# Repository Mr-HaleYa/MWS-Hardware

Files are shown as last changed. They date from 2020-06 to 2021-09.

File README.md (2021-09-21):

# My Water Site - Hardware

[3D Files](3D_models/README.md)

# PCB

### [V4.0](https://github.com/Mr-HaleYa/MyWater_Misc/tree/master/PCB#v40)

Front             |  Back
:-------------------------:|:-------------------------:
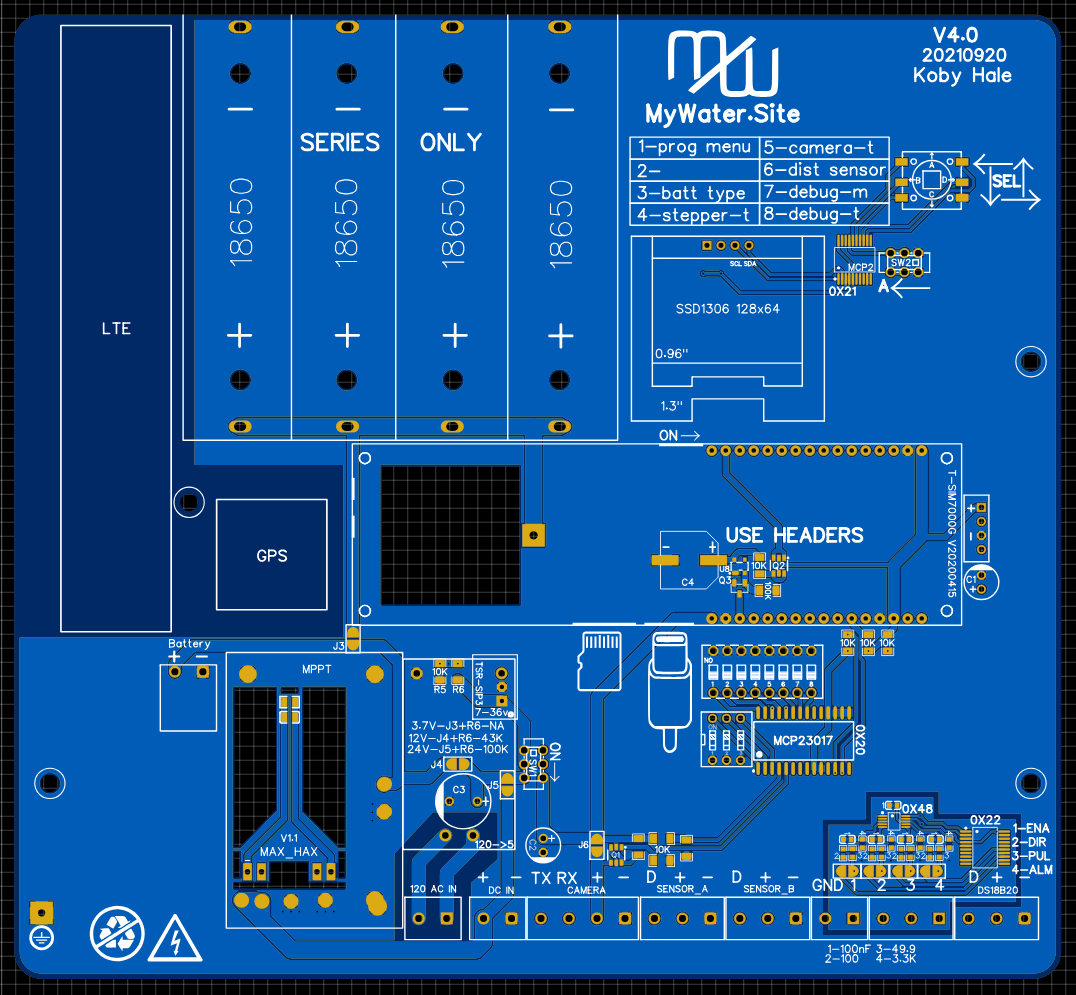
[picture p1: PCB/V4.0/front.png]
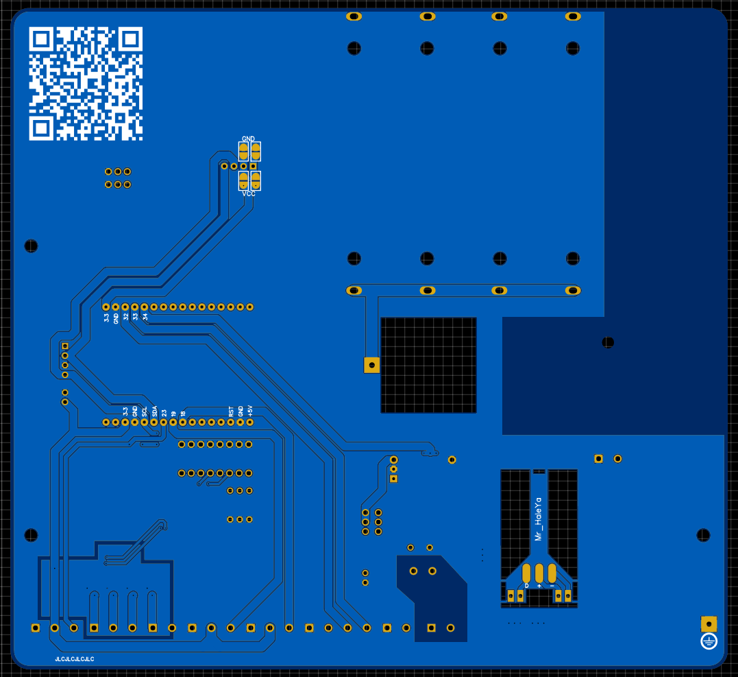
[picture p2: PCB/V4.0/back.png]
  |  

### [V3.2](https://github.com/Mr-HaleYa/MyWater_Misc/tree/master/PCB#v32)

Front             |  Back
:-------------------------:|:-------------------------:
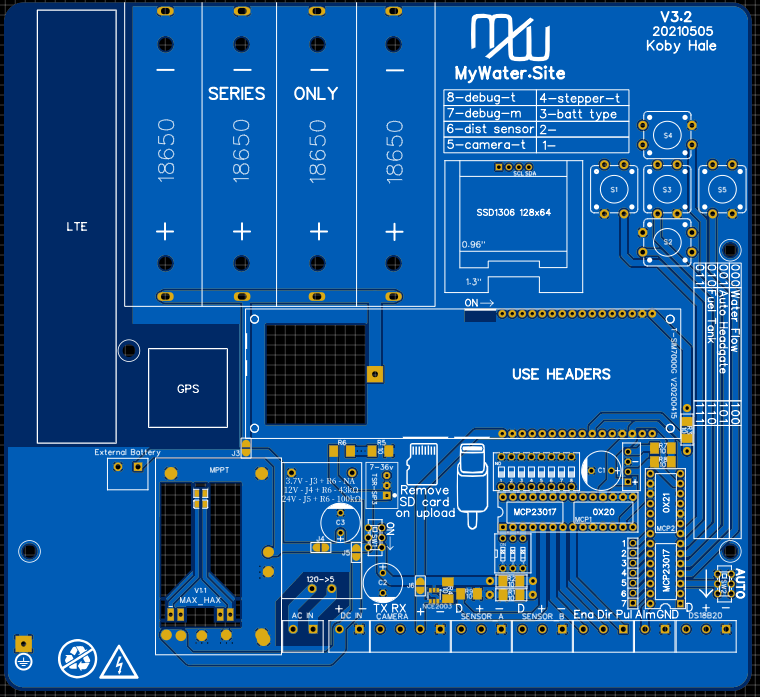
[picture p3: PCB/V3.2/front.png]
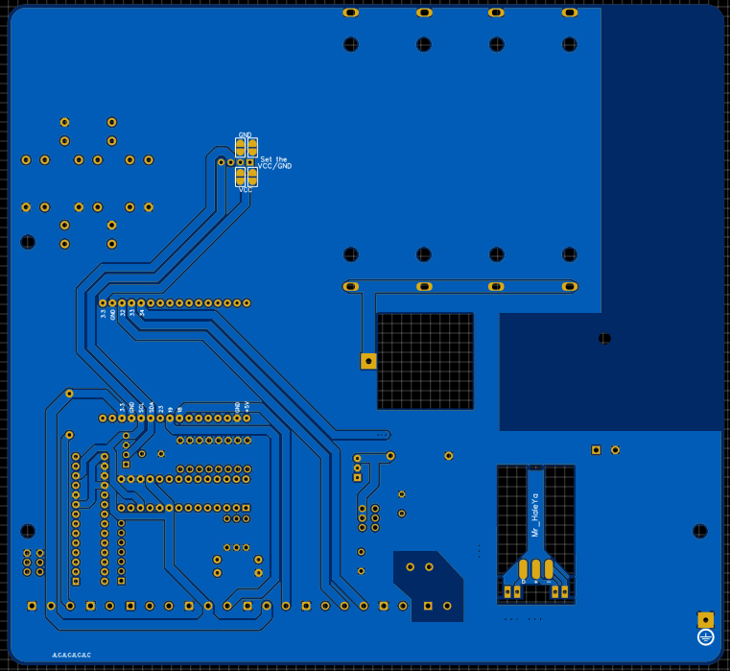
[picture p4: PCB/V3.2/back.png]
  |  

### [V3.1](https://github.com/Mr-HaleYa/MyWater_Misc/tree/master/PCB#v31)

Front             |  Back
:-------------------------:|:-------------------------:
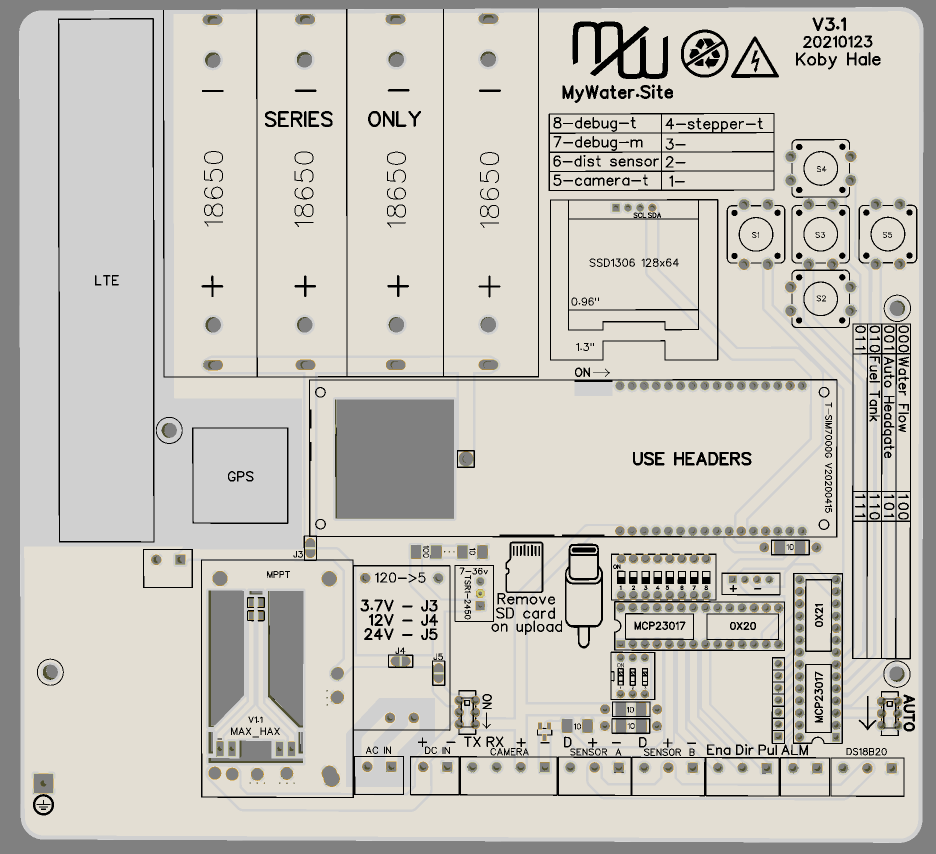
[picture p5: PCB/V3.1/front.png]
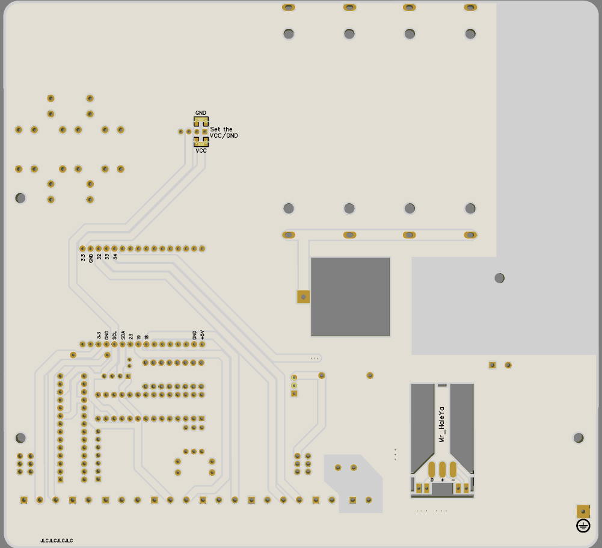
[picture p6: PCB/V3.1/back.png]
  |  

### [V3.0](https://github.com/Mr-HaleYa/MyWater_Misc/tree/master/PCB#v30)

Front             |  Back
:-------------------------:|:-------------------------:
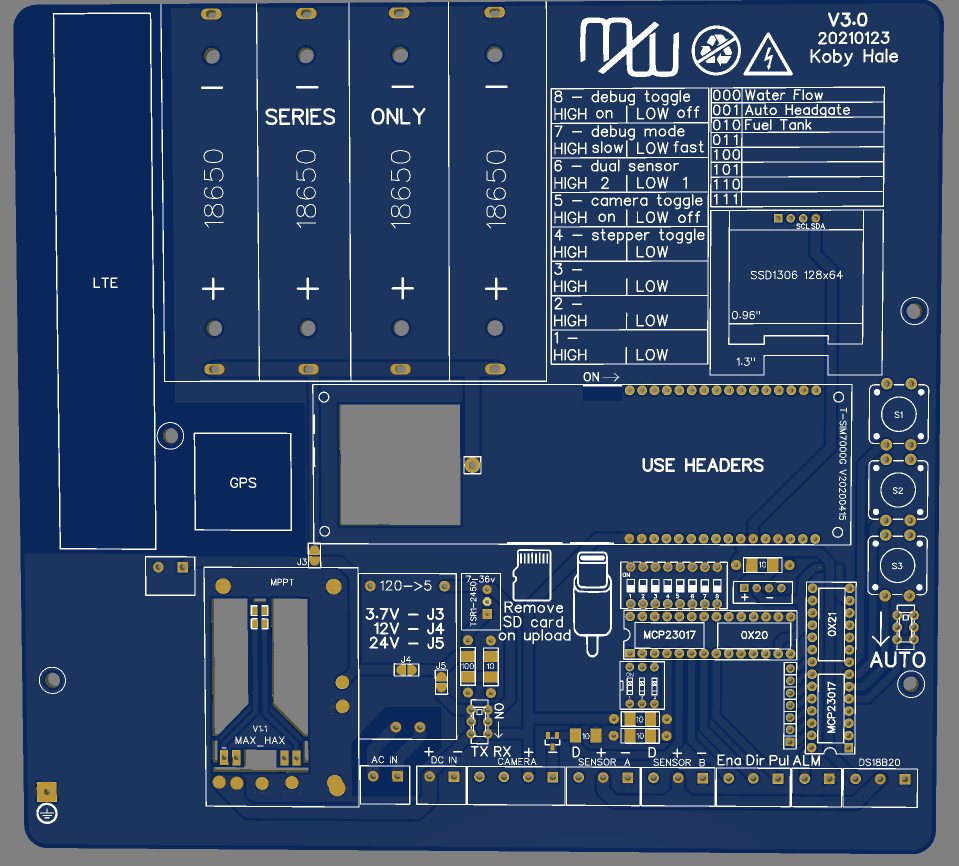
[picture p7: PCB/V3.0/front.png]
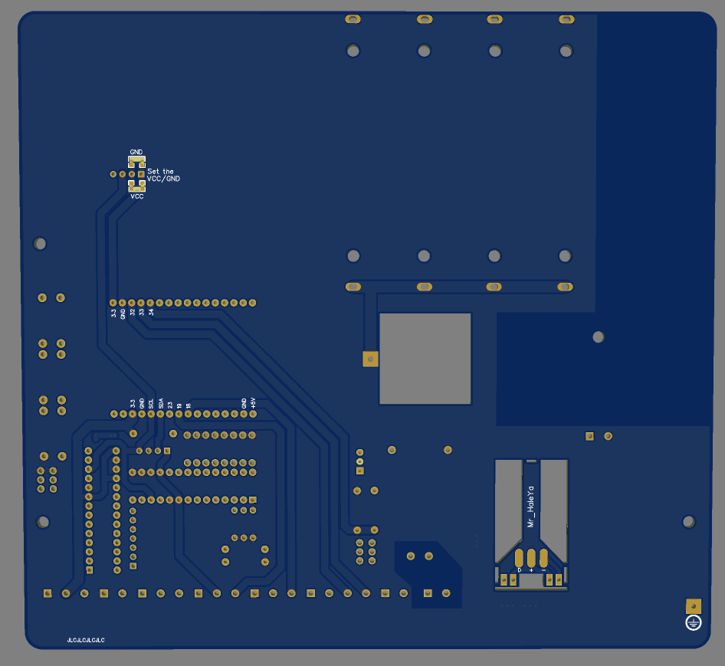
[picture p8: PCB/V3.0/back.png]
  |  

### [V2.0](https://github.com/Mr-HaleYa/MyWater_Misc/tree/master/PCB#v20)

Front             |  Back
:-------------------------:|:-------------------------:
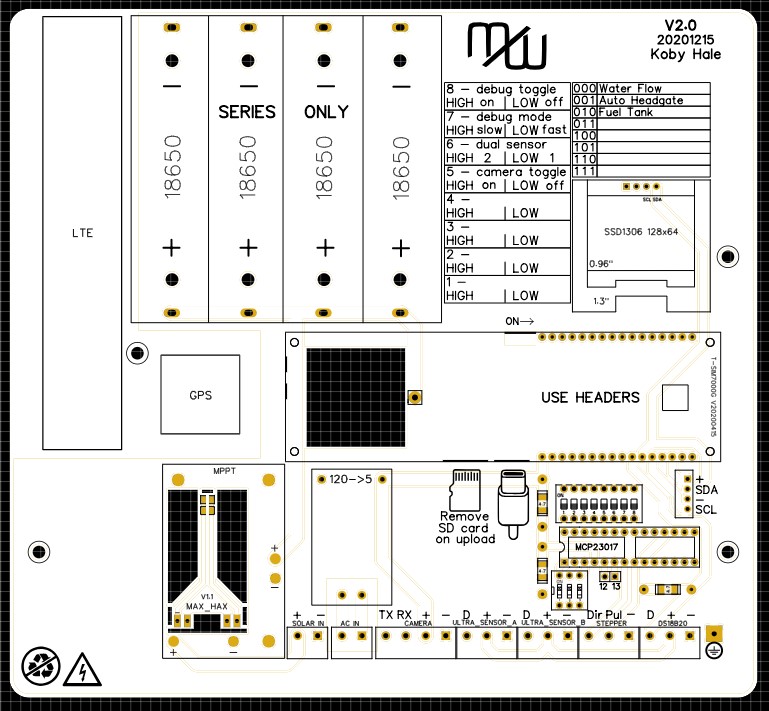
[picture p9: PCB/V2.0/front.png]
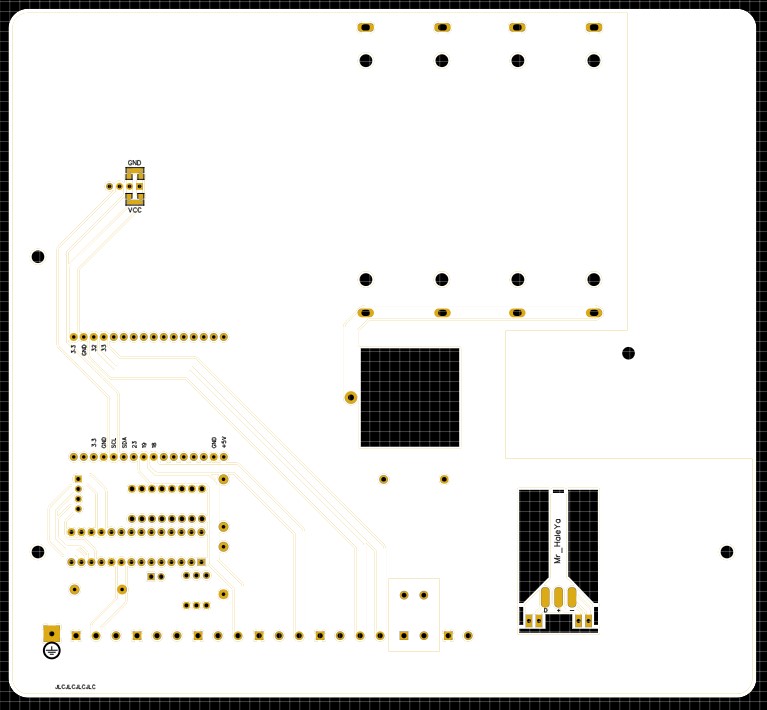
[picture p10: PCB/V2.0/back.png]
  |  

### [V1.2](https://github.com/Mr-HaleYa/MyWater_Misc/tree/master/PCB#v12)

Front             |  Back
:-------------------------:|:-------------------------:
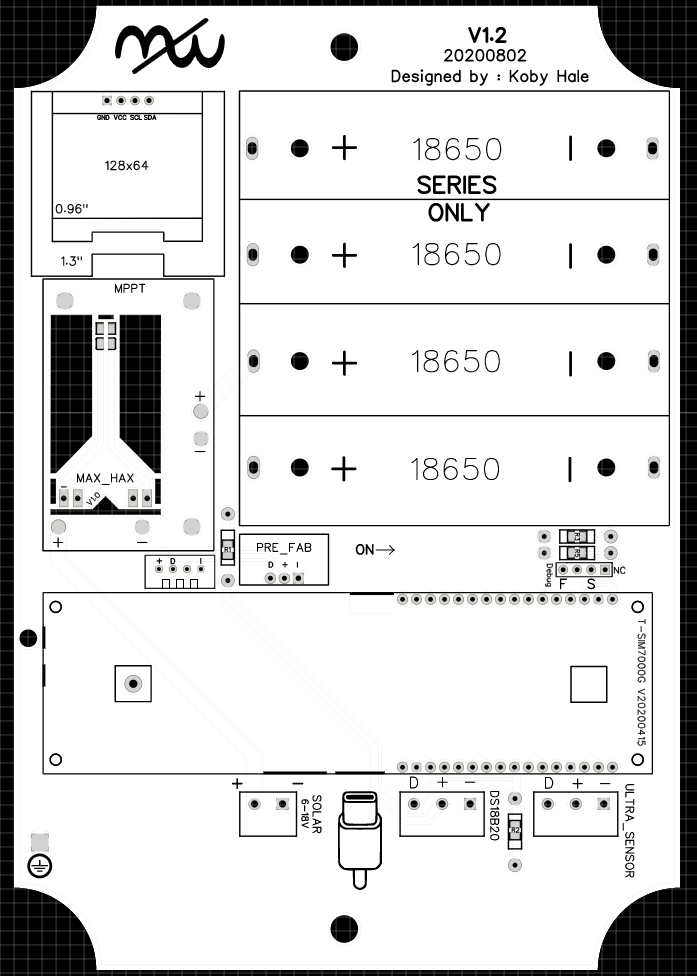
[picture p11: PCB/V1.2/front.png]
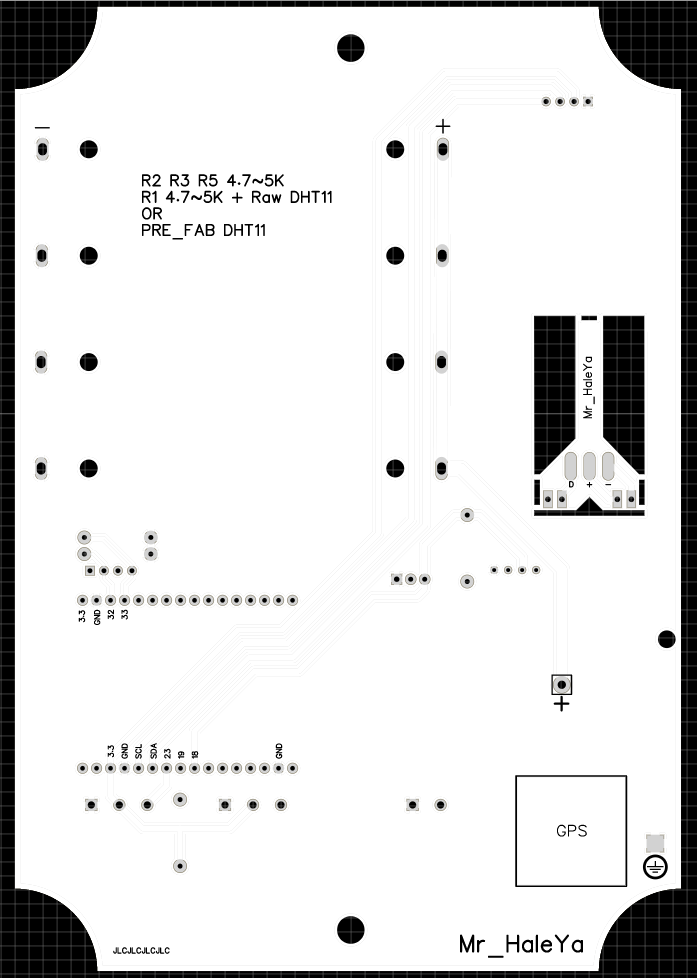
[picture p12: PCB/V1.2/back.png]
  |  

### [V1.1](https://github.com/Mr-HaleYa/MyWater_Misc/tree/master/PCB#v11)

Front             |  Back
:-------------------------:|:-------------------------:
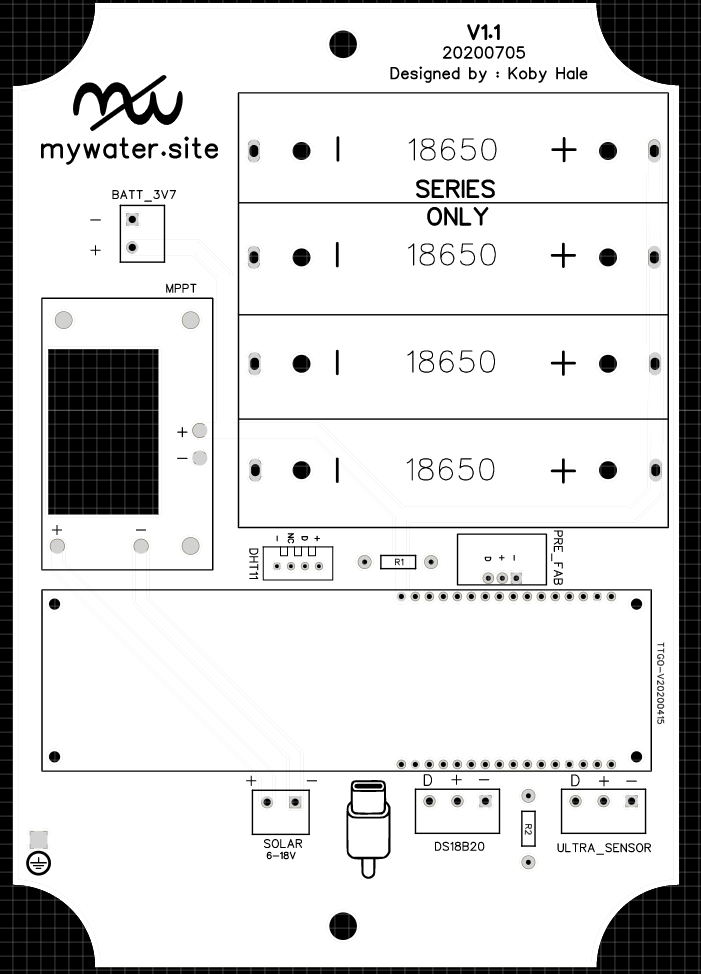
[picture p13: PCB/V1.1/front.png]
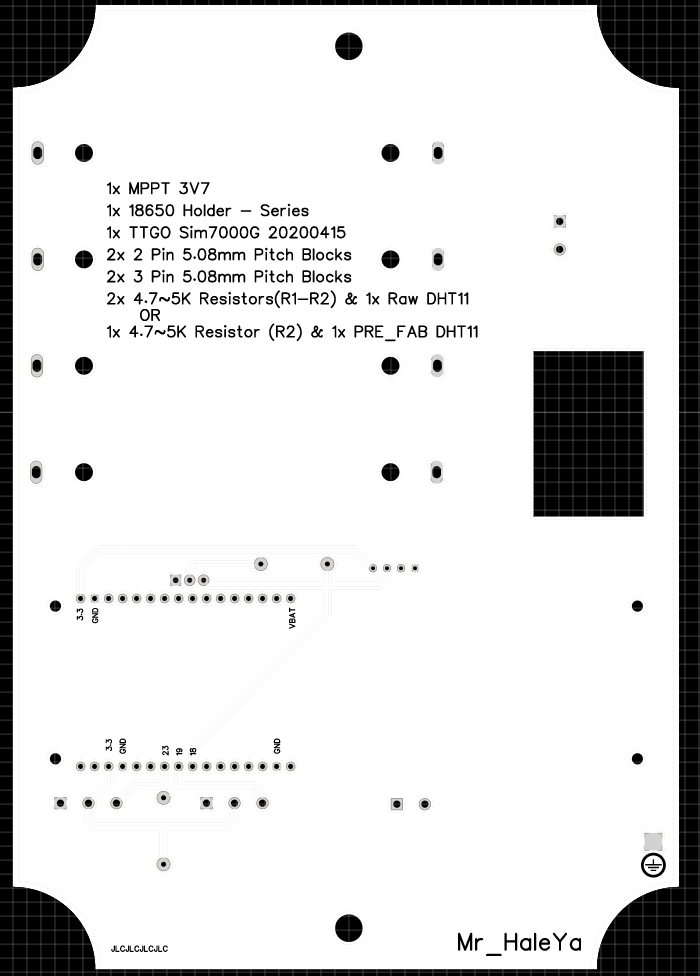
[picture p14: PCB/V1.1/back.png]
  |  

### [V1.0](https://github.com/Mr-HaleYa/MyWater_Misc/tree/master/PCB#v10)

Front             |  Back
:-------------------------:|:-------------------------:
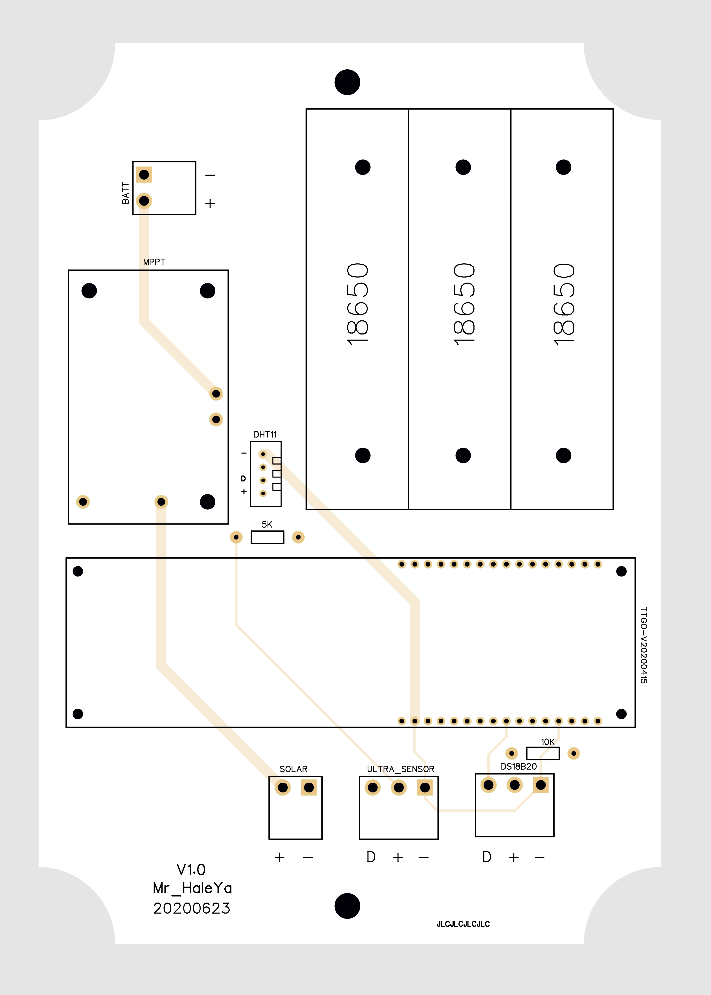
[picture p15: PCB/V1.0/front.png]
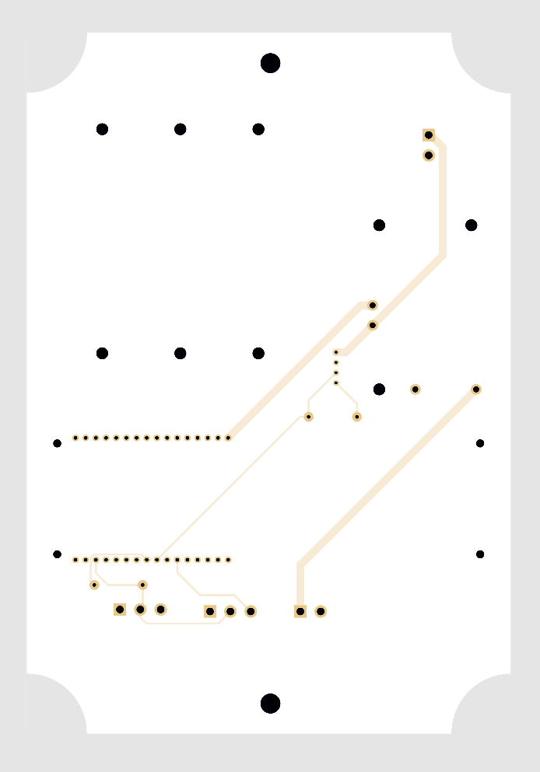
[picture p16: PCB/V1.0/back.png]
  |

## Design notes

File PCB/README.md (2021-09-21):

# Changelog

## [V1.0](https://github.com/Mr-HaleYa/MyWater_Misc/tree/master/PCB/V1.0)
The first version with 4 short circuits and the wrong ping was assigned to the Ultrasonic sensor, and a lot of the pins were backward... 

## [V1.1](https://github.com/Mr-HaleYa/MyWater_Misc/tree/master/PCB/V1.1)
Improved the routes, thickened the charging traces, added some more Silk Screen Decals, and fixed polarity issues.

##### Added
- 4 Battery pack
- option to use Pre-Fab DHT11
- MPPT heat cutout
- Company LOGO

##### Fixed
- Short Circuits 
- corrected Sensor pin
- polarity of pins

## [V1.2](https://github.com/Mr-HaleYa/MyWater_Misc/tree/master/PCB/V1.2)
Changed the pins that power the board to use the pins on the back of the TTGO so we have all battery protections that are included. Altered the MPPT heat cut out to have a second small PCB built inside of it with small bridges so it can be removed and used as the temp sensor for the Ultrasonic Sensor.

##### Added 
- Connectors for battery pad on the back of ttgo
- Backward battery protection
- overcharge Protection
- Over-Discharge protection
- 3A overcurrent protection
- on/off switch
- 0.96" or 1.3" OLED Debug screen
- Debug_S or Debug_F jumper headers
- SMD resistor options
- Mini PCB in MPPT cutout

##### Fixed
- location of terminal blocks 
- grounding of solar pins
- grounding of MPPT
- battery pack orientation 

## [V2.0](https://github.com/Mr-HaleYa/MyWater_Misc/tree/master/PCB/V2.0)
A new format for a new box. Almost all the hardware is the same except for the addition of an MCP23017 multiplexer that adds 16 more GPIO pins and uses I2C, It is mainly used for a set of 2 dip switches that set station settings and info. Also changed out the DHT11 for an AM2320 because the freezing temperatures were breaking the sensor.

#### Added
- MCP23017 multiplexer
- 8 pin dip for station settings
- 3 pin dip for setting station type
- am2320 temp / humidity sensor
- 120VAC -> 5VDC for mains power

## [V3.0](https://github.com/Mr-HaleYa/MyWater_Misc/tree/master/PCB/V3.0)
Fixed a lot of small problems with the new format. Added 3 pushbuttons for navigation a menu on the screen for config and control of the station. Added another MCP23017 for even more GPIO pins for the pushbuttons. Also added a ton of little improvements.

#### Added
- Another MCP23017 multiplexer
- 3 pushbuttons for screen control
- external battery header
- jumper pads for setting power source
- switch to control when in config mode
- voltage divider to measure external DC voltage
- switch to turn on/off when using external DC
- voltage divider to check if the 5Vin rail has power
- Low-Side on/off switch for the camera using small MOSFET
- 12V MPPT solar charger for charging external 12V pack

## [V3.1](https://github.com/Mr-HaleYa/MyWater_Misc/tree/master/PCB/V3.1)
Moved the buttons and added 2 more for a total of 5 push buttons.

#### Added
- 2 more push buttons

## [V3.2](https://github.com/Mr-HaleYa/MyWater_Misc/tree/master/PCB/V3.2)
Aimed to fix the bugs that were killing boards that used external DC. Fixed layout of DC on/off to cut power to the voltage divider used to measure the external battery voltage. Added filter caps to DC_IN, 5V, and 3.3V so they should all be smooth voltages (470uF 35V electrolytic). Changed the camera power to high side switching instead of low side switching because it was causing problems. 

#### Added
- 10K pull-ups to SDA and SCL
- filter caps to DC_IN, 5V, and 3.3V (470uF 35V electrolytic)
- dual MOSFET for the high side switch (N+P MOSFET)
- solder jumper (j6) to make the camera always on

#### Fixed
- Camera power to high side switching instead of low side switching
- layout of DC on/off to cut power to the voltage divider used to measure external battery voltage
- camera power to high side switching
- larger solder jumper for setting screen power and GND

## [V4.0](https://github.com/Mr-HaleYa/MyWater_Misc/tree/master/PCB/V4.0)
Aimed at resolving the problem of boards getting stuck in a bricked state when being charged by a solar panel from a dead state. The monitor uses a duel MOSFET to invert the signal of the OBLED pin, this then charges an RC circuit when the OBLED is on. after a threshold voltage is met a voltage monitor switches its output to HIGH causing the RST pin to be pulled LOW and the entire device to reboot. In addition, another circuit was added to measure 4-20ma sensors. The circuit uses an ASD1115 chip to measure up to 4 analog sensors at a time and transmits the data using I2C.

#### Added
- Added ADS1115 to measure 4 Analog inputs for 4-20ma sensors
- Created a bricked state detection circuit, will reboot ESP if OBLED is on for more than 30s
- Added QR code that links to Git Repo

#### Fixed
- Fixed silk screen text of dips positions
- TSR overlaps 120->5V transformer due to only one being usable at a time
- All 1206 SMD pads have been reduced in size to true 1206 size
- Moved CHTA31 to be less in the way of dips

##### Changes
- C1 and C2 replaced with smaller 10V caps
- Changed MCP23017 from TH to SMD
- Replaced the secondary MCP with 2 MCP23008 SMD chips
- Changed 5 push button group to a single package 5 button joystick
- Changed terminal block connectors to vertical sockets
- Removed 3-pin dip state table
- Reduced amount of silkscreen text
- Optimized and cleaned up wire runs

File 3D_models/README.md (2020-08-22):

# Notes

### Solar_Shield1.stl

Used to shield the ultrasonic sensor temperature probe from the Sun and rain has 1-inch female and 1-inch male connectors.
- 15% infill / 3D honeycomb / no support
___

### Solar_Shield2.stl

Solar shield for ultrasonic sensor to prevent damage to the external plastic and aid in the reduction of thermal shock that could potentially cause spikes in readings.
- 15% infill / 3D honeycomb / no support
___

### Solar_Shield3.stl

Shielding for DS18B20, attaches directly to a waterproof pass-through at the bottom of the box. Helps reduce massive spikes in temperature when the Sun hits the probe directly.
- 15% infill / 3D honeycomb / no support

___

### Coupling.stl

Three-quarter inch two 1in male coupling used to attach the Solar Shield to the ultrasonic sensor, it has been filled with epoxy to create a waterproof seal between the attached cables and the sensor. 
- 15% infill / 3D honeycomb / no support
___

### Solar_Mount_Arm.stl

Top arm used to mount the solar panel. It attaches directly to the back of the solar panel.
- 20% infill / 3D honeycomb / no support
___

### Solar_Mount_Arm_2.stl

The bottom support arm for solar panel attaches to the bottom of the top mount providing extra support and stability hopefully enough to prevent damage in strong winds.
-  20% infill / 3D honeycomb / no support
___

### Solar_Mount_Bracket.stl

Top solar panel mount bracket, sloped at a 26-degree angle to provide optimal charging at our latitude. Made to be mounted to a 2in pole using a 2 3/8 inch U bolt.
- 50% infill / 3D honeycomb / 55° support
___

### Solar_Mount_Bracket_2.stl

Bottom solar panel mount bracket. Made to be mounted to a 2-inch Pole a 2 3/8 inch U bolt
- 50% infill / 3D honeycomb / 55° support

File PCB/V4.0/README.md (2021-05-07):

  | 
:---:|:---:
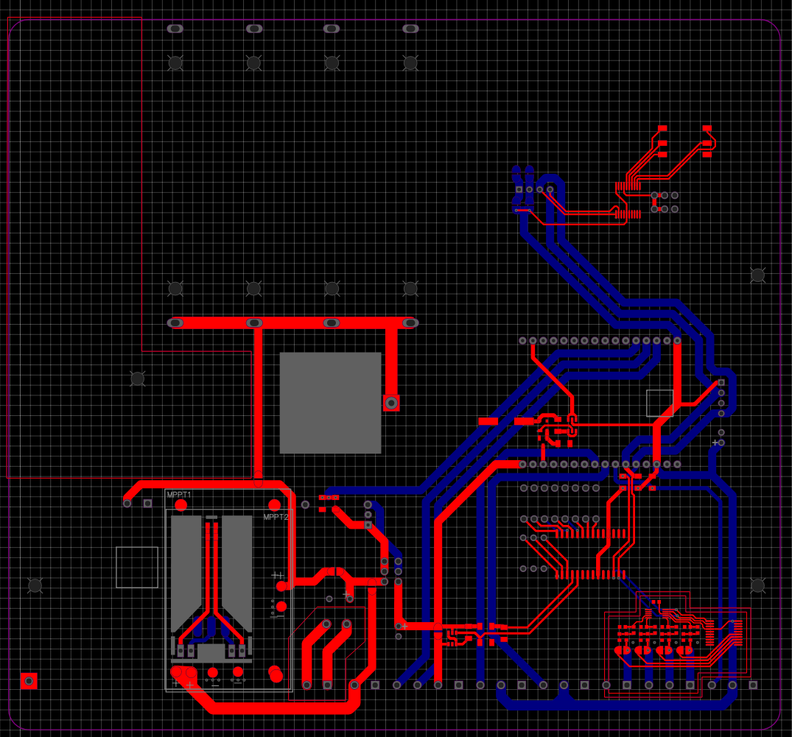
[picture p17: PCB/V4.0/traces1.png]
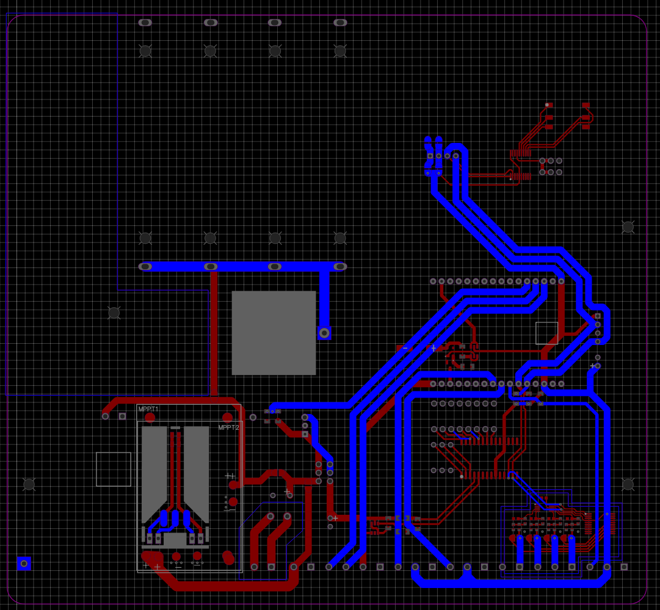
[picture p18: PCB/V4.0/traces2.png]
 |  

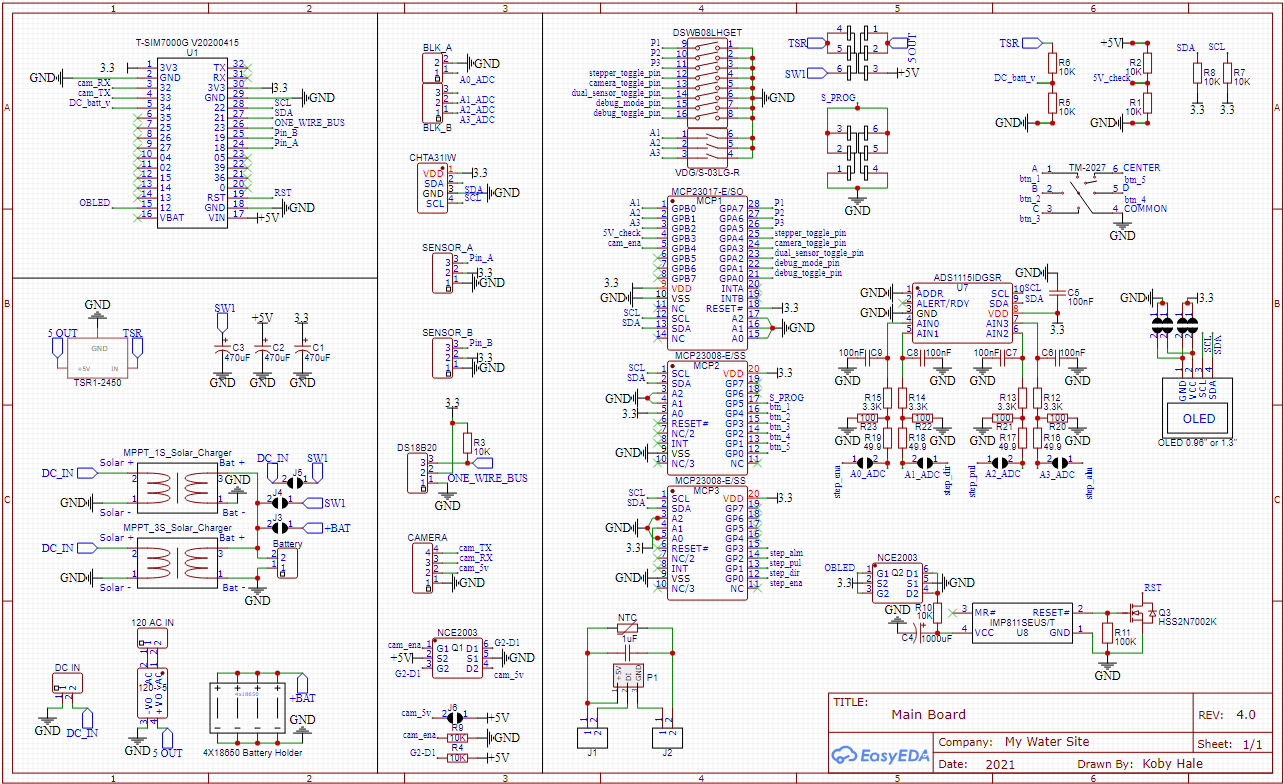
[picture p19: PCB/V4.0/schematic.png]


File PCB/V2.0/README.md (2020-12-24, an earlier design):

  | 
:---:|:---:
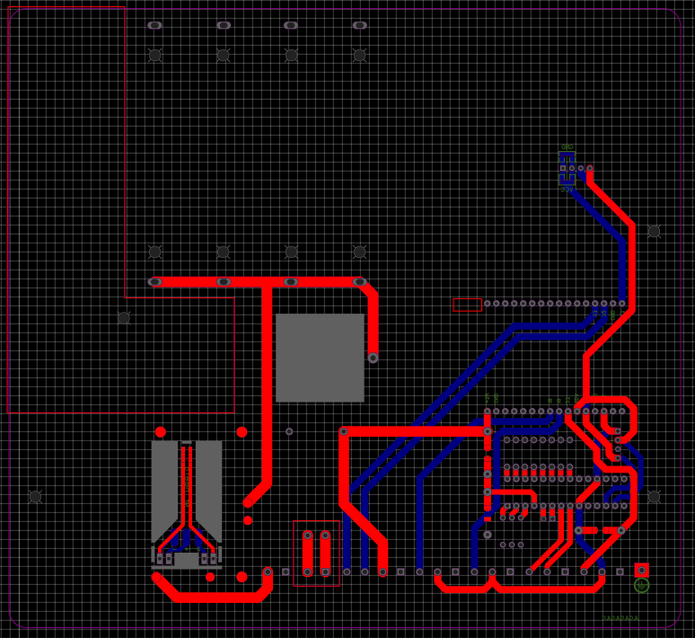
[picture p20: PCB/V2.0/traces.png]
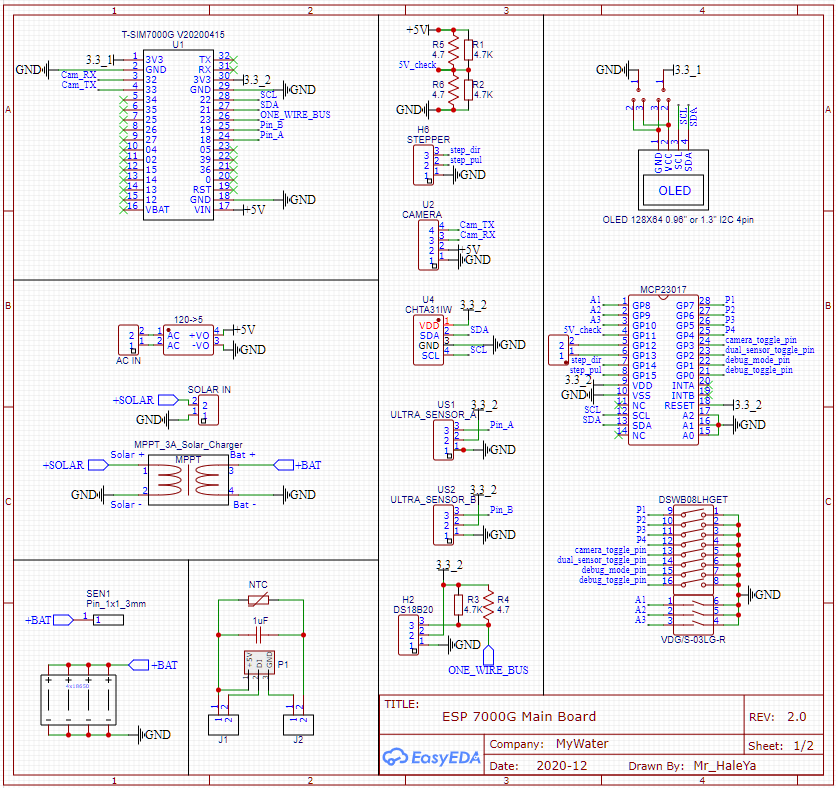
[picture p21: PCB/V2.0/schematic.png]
 |

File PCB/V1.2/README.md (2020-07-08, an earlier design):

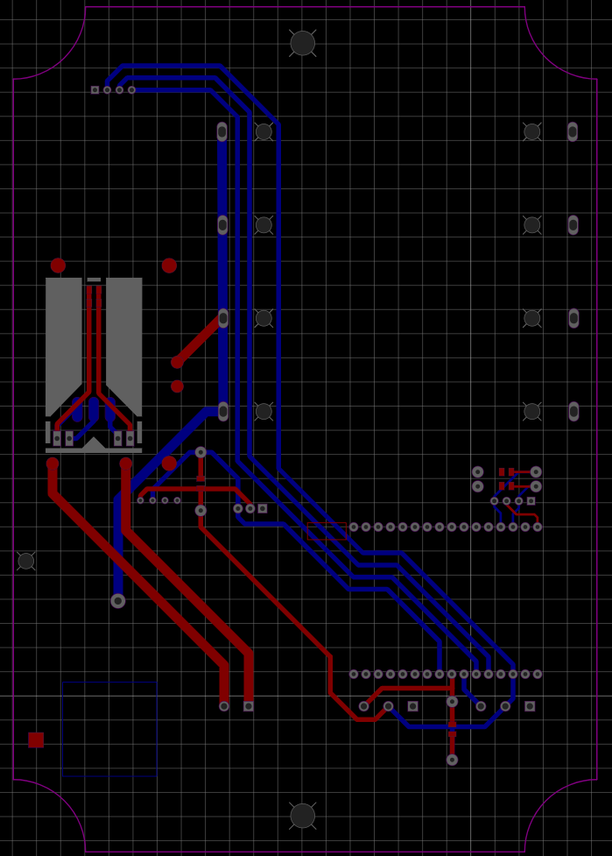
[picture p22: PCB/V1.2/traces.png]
  |   | 
:--------------:|:--------------:|:--------------:

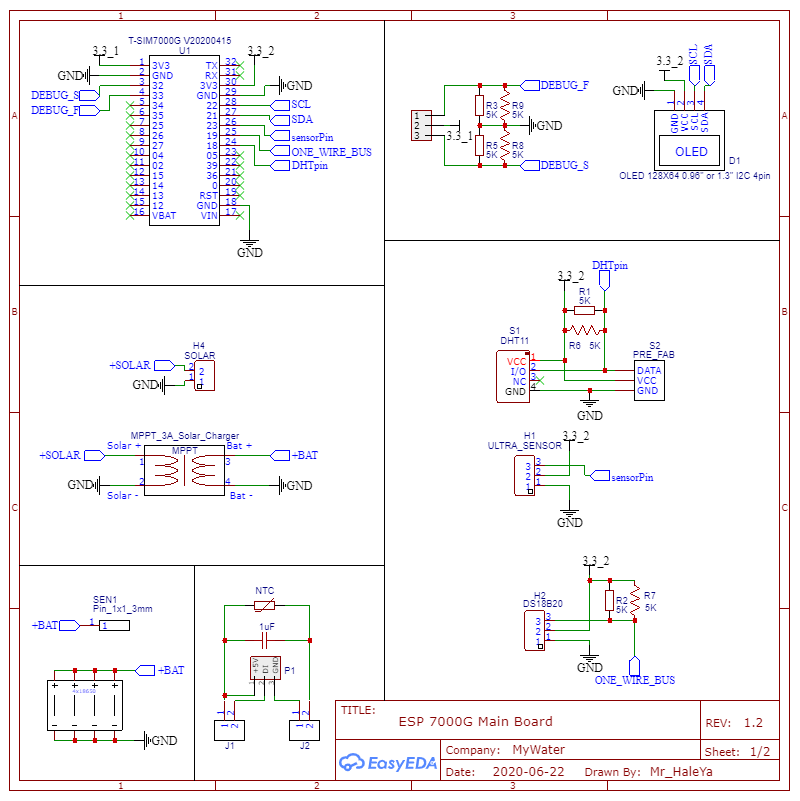
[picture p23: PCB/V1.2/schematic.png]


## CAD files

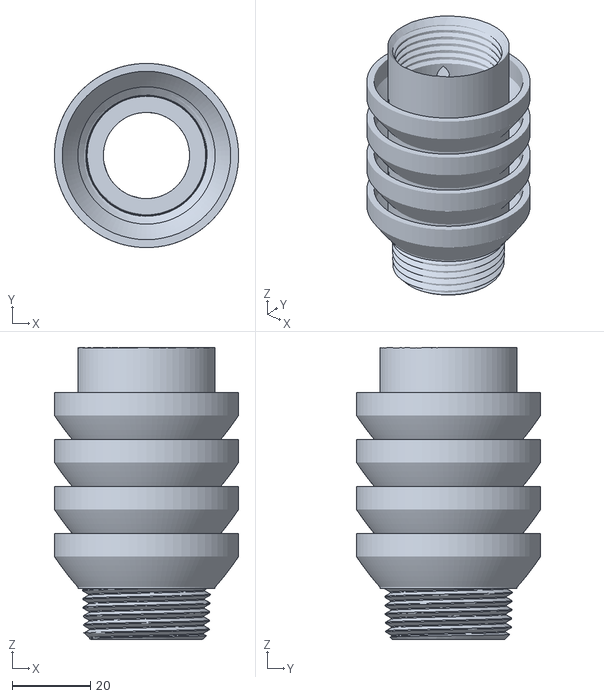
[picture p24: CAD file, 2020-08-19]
3D_models/Solar_Shield1.stl
47.0 x 47.0 x 74.5

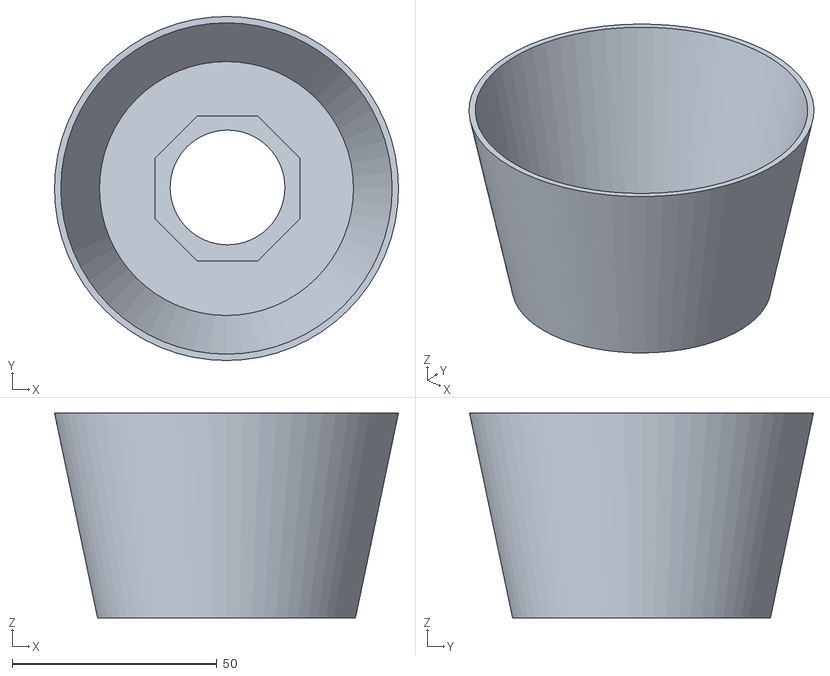
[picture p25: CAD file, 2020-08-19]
3D_models/Solar_Shield2.stl
84.0 x 84.0 x 50.0

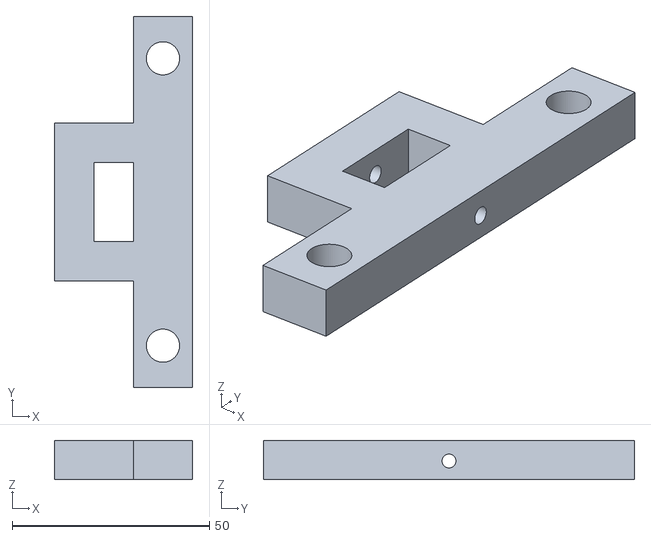
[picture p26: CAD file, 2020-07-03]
3D_models/Solar_Mount_Bracket_2.stl
35.0 x 94.0 x 10.0

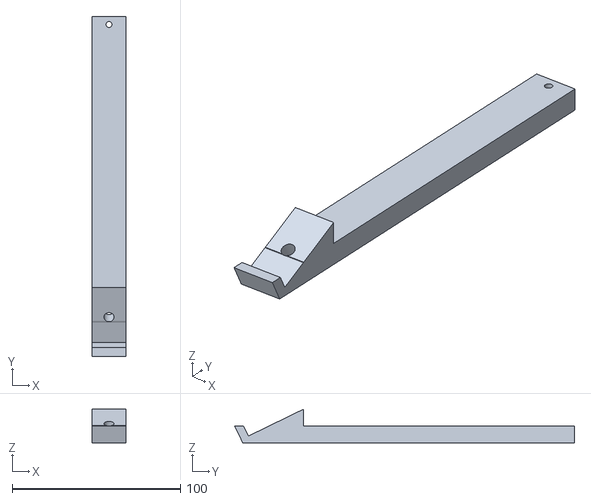
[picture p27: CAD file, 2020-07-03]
3D_models/Solar_Mount_Arm_2.stl
20.0 x 201.9 x 19.9

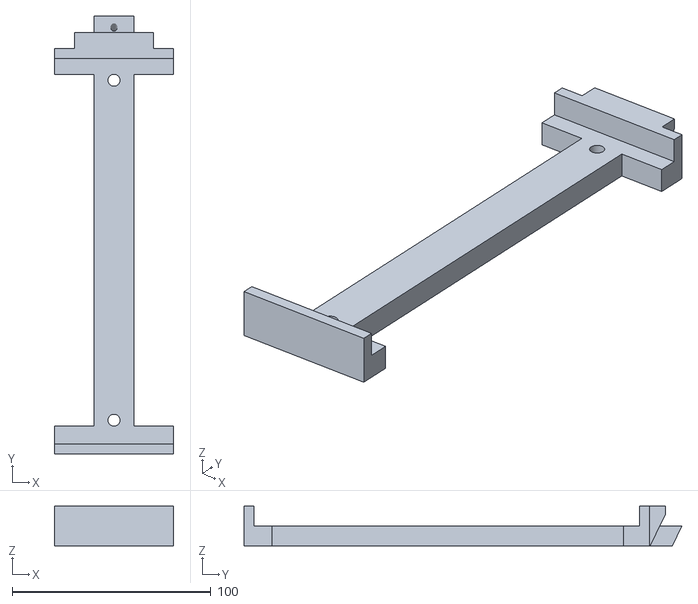
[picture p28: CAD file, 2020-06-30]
3D_models/Solar_Mount_Arm.stl
60.0 x 220.4 x 20.0

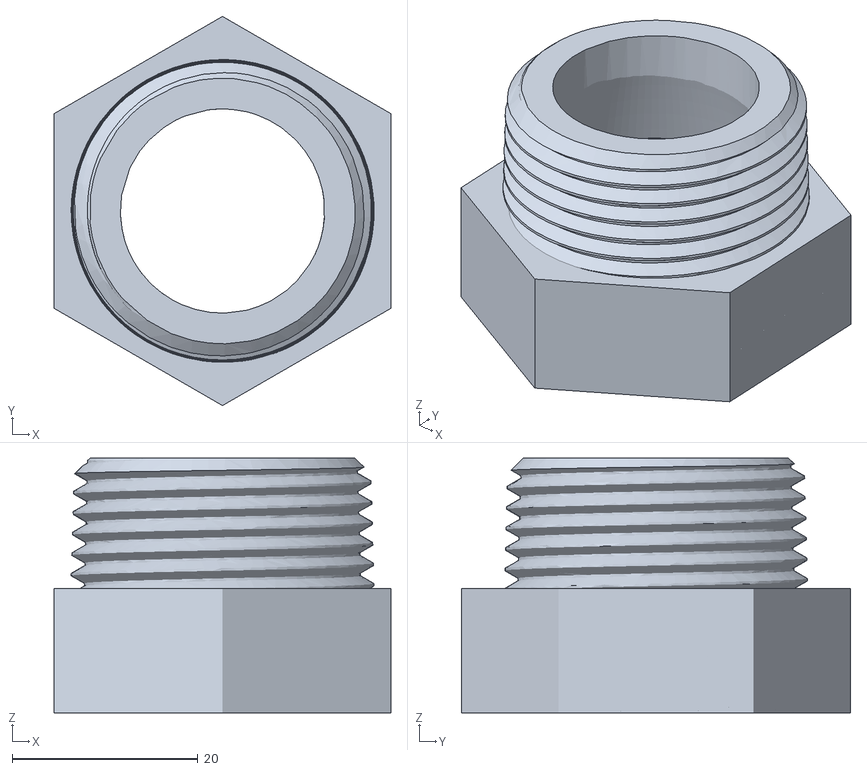
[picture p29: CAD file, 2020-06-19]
3D_models/Coupling.stl
36.3 x 41.9 x 27.4

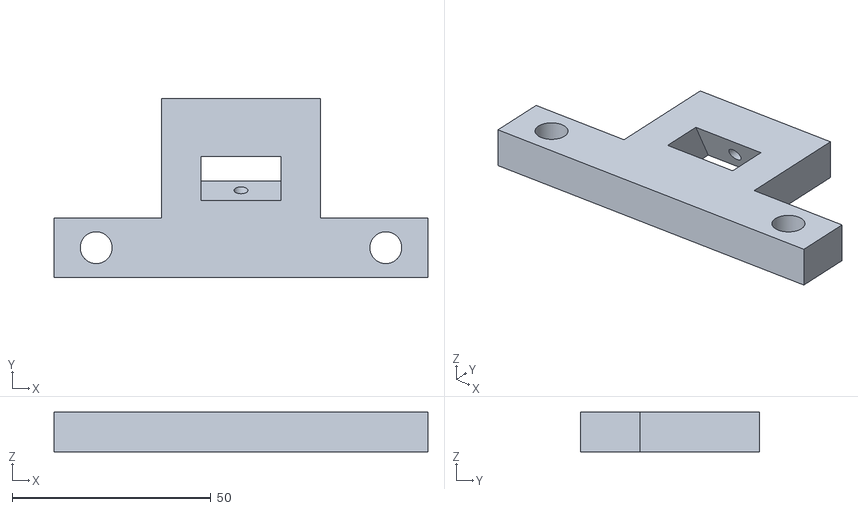
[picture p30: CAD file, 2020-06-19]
3D_models/Solar_Mount_Bracket.stl
94.0 x 45.0 x 10.0

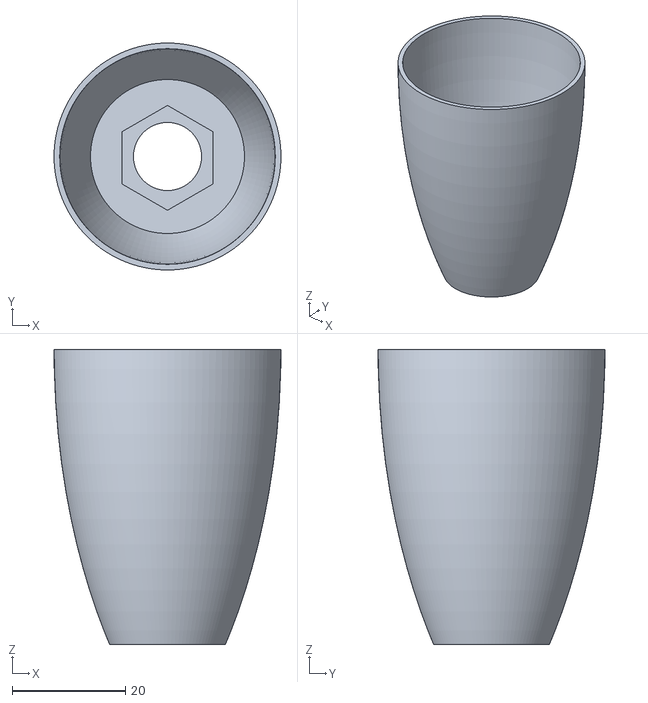
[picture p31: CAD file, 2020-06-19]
3D_models/Solar_Shield3.stl
40.0 x 40.0 x 52.0

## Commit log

2020-06-19 Add solar shield files
    [Solar_Shield1.stl, Solar_Shield2.stl, Solar_Shield3.stl]
2020-06-19 more files
    [Solar_Mount_Arm.stl, Solar_Mount_Bracket.stl]
2020-06-25 Update Solar_Mount_Arm.stl
    shorter nub length
    [Solar_Mount_Arm.stl]
2020-06-27 Delete 30mm_fan_shroud.stl
    no longer need a fan after more testing was done
    [30mm_fan_shroud.stl]
2020-06-30 Shortened by 2mm
    [Solar_Mount_Arm.stl]
2020-06-30 added more support and pin hole
    [Solar_Mount_Arm.stl]
2020-07-03 More SP support
    [Solar_Mount_Arm_2.stl, Solar_Mount_Bracket_2.stl]
2020-07-08 V1.1 update to PCB
2020-08-03 Added V1.2 PCB files
2020-08-19 Update Solar_Shield2.stl
    made the sides a flat angle instead of sloped instead of rounded so that the printer will stop failing at an angle shifting layer. Also reduced the wall thickness to 2mm instead of 3 mm since it does not need to be that thick. Overall the print time was reduced by 43 min
    [Solar_Shield2.stl]
2020-08-19 Update Solar_Shield1.stl
    Fixed top threading so it wasnt overhanging as much so it wont web as bad
    [Solar_Shield1.stl]
2020-12-24 new pcb V2.0
